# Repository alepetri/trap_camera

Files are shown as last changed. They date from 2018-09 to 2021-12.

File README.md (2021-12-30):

# Raspberry Pi Trap Camera

A custom Trap Camera that uses a Passive Infrared trigger to turn on an Infrared Illuminator and start taking photos via a camera with No IR Filter!

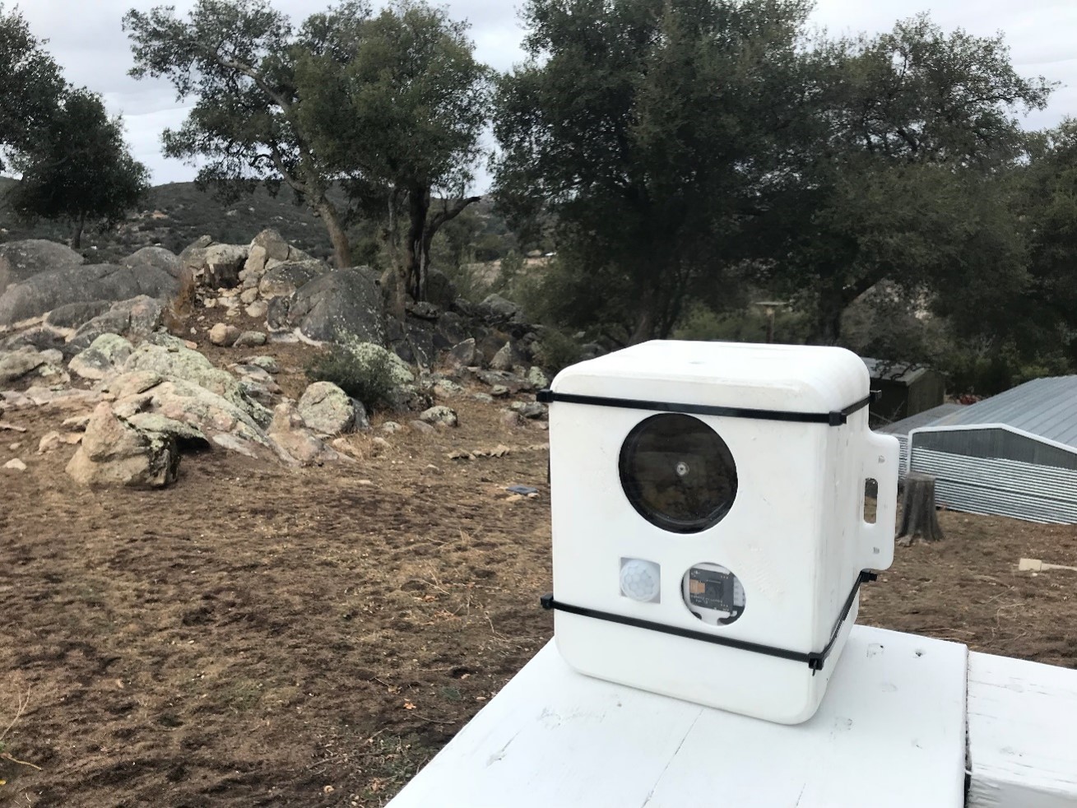
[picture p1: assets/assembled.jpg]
Assembled View


*Gray Fox caught in the act of going through my compost*
Gray Fox in Compost

## Design
Rotation View

Parts List:
- Electronics
    - Raspberry Pi
    - Pi NoIR Camera
    - Passive IR Sensor
    - IR Illuminator
    - 12V Battery
    - Power Relay (GPIO Controllable)
    - 12V to 5V Power Converter
    - Button
    - LED
    - USB External Storage
- Mechanical
    - Polycarbonate Cutouts for Illuminator and Camera
    - O-Ring
    - Pins/ Rods for Hinges
    - Various Fasteners
    - Wiring

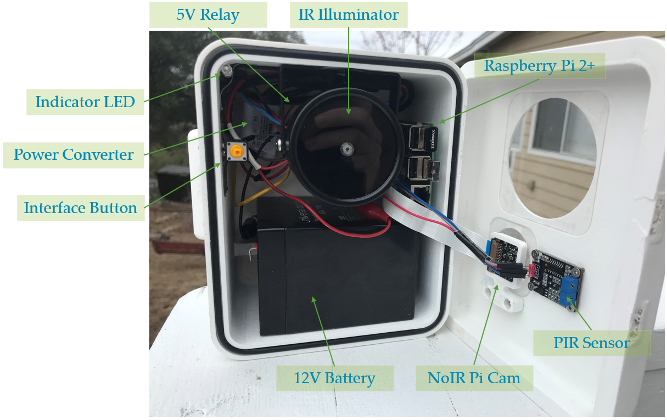
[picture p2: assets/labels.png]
Annotated Veiw


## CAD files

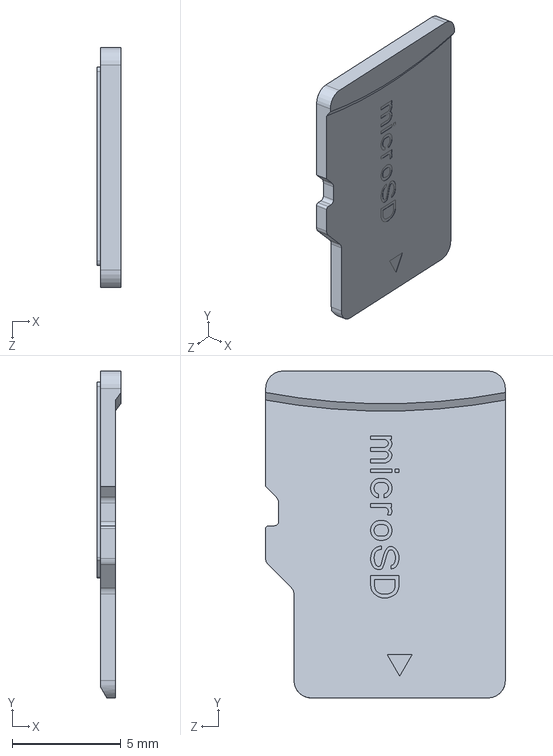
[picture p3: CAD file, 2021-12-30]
CAD/Pi/raspberry_pi_B+_(microsd).SLDASM
1.10 x 15.0 x 11.0 mm

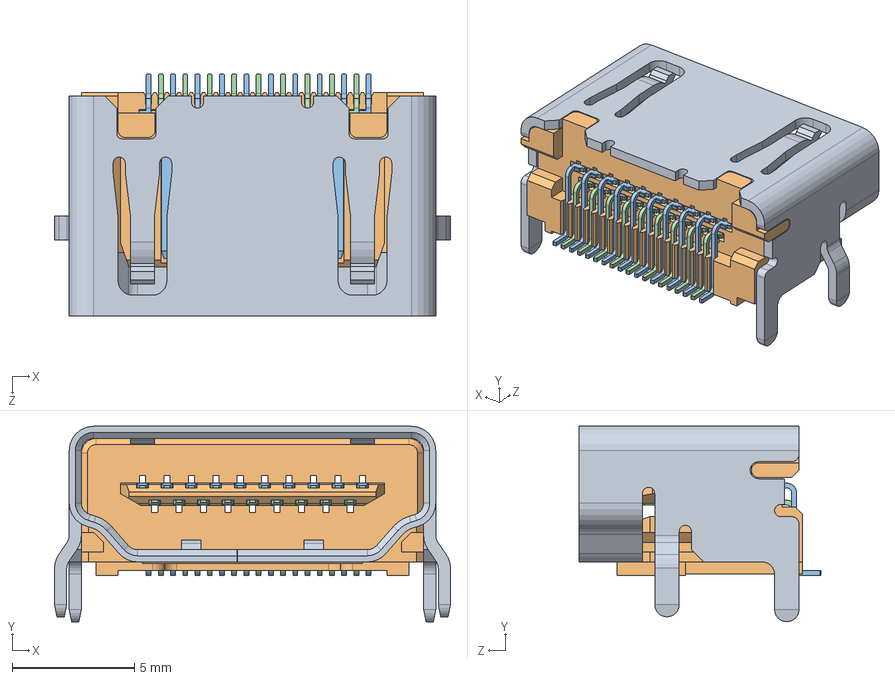
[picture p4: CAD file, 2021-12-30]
CAD/Pi/raspberry_pi_B+_(HDMI_socket).SLDASM
16.2 x 8.00 x 9.90 mm
raspberry_pi__HDMI_socket_cover
raspberry_pi__HDMI_socket_inside
raspberry_pi__HDMI_socket_large_pin x 10
raspberry_pi__HDMI_socket_small_pin x 9

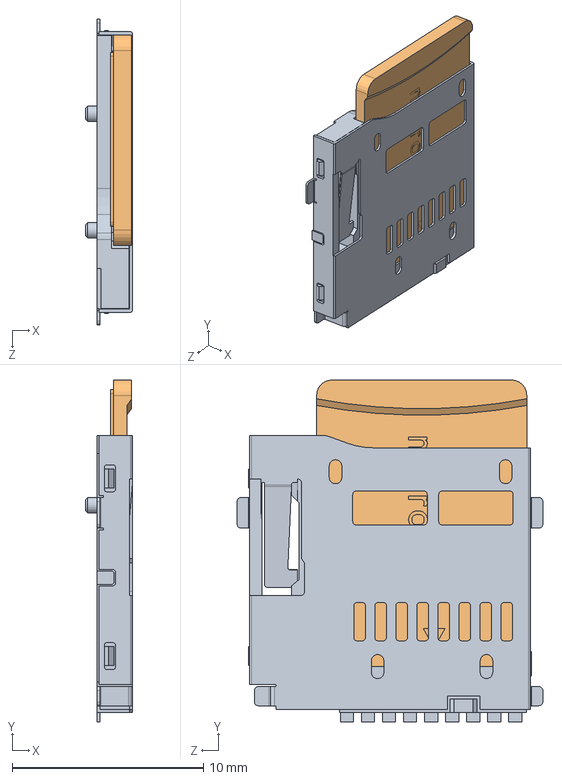
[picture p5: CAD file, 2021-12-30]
CAD/Pi/raspberry_pi_B+_(microsd_slot).SLDASM
2.44 x 17.9 x 16.0 mm
raspberry_pi_B+_(slot)
raspberry_pi_B+_(microsd)

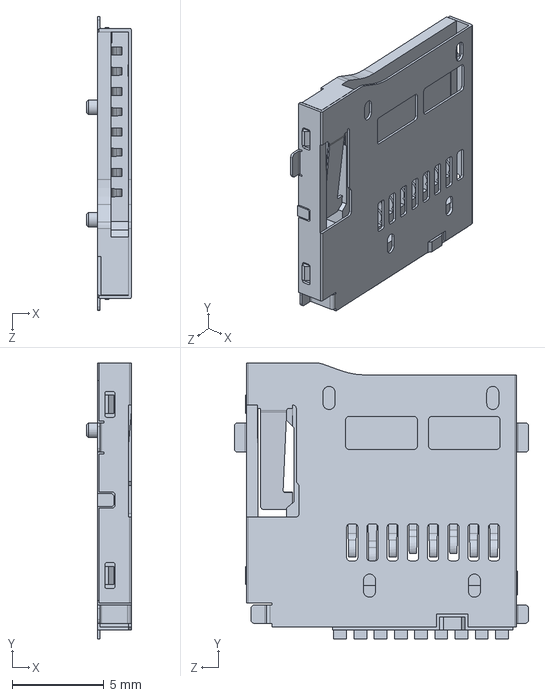
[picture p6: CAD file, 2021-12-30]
CAD/Pi/raspberry_pi_B+_(slot).SLDASM
2.44 x 15.0 x 16.0 mm

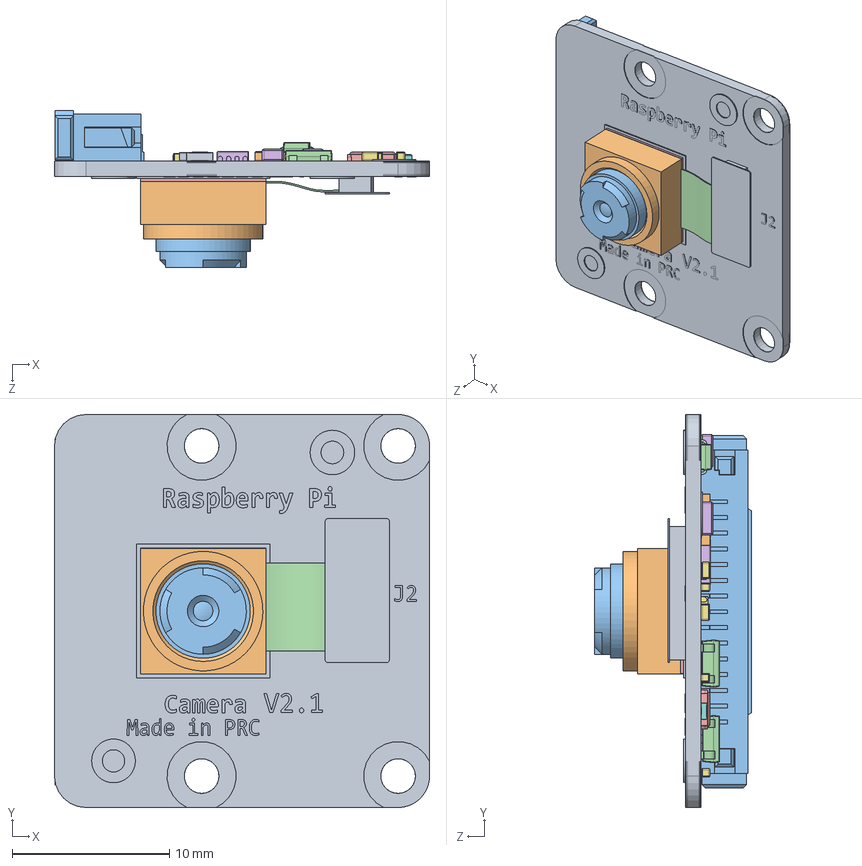
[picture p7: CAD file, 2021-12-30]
CAD/PiCam/RspCameraMia.SLDASM
23.9 x 25.0 x 9.96 mm
PicameraPCB
OVA5647_Housing
OVA5647_Lens_FOV
ribbon_cam
CCD
CAPC-0805-T0.75-BN x 2
CAPC-0402-T0.55-BN x 10
RESC-0402 x 3
RESC-0603 x 2
RESC-1210
c-1-1734248-5-e-raspberry_display
SOT23-5 x 3
KX7 SMD Quartz Crystal Resonator 3.2x2.5mm
c6aaa
4pin_smd x 3

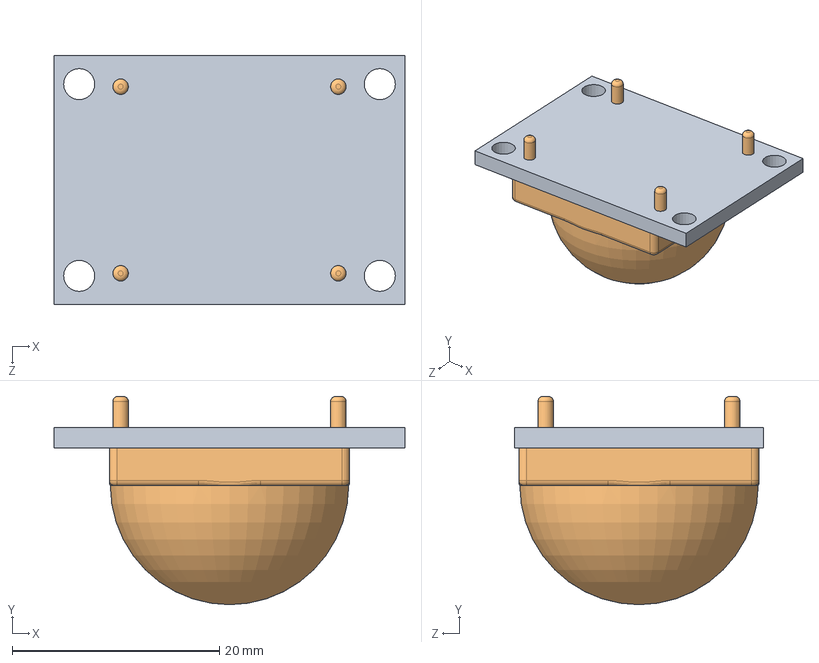
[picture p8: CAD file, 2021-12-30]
CAD/PIR.SLDASM
33.9 x 20.1 x 24.0 mm
sensor
lens

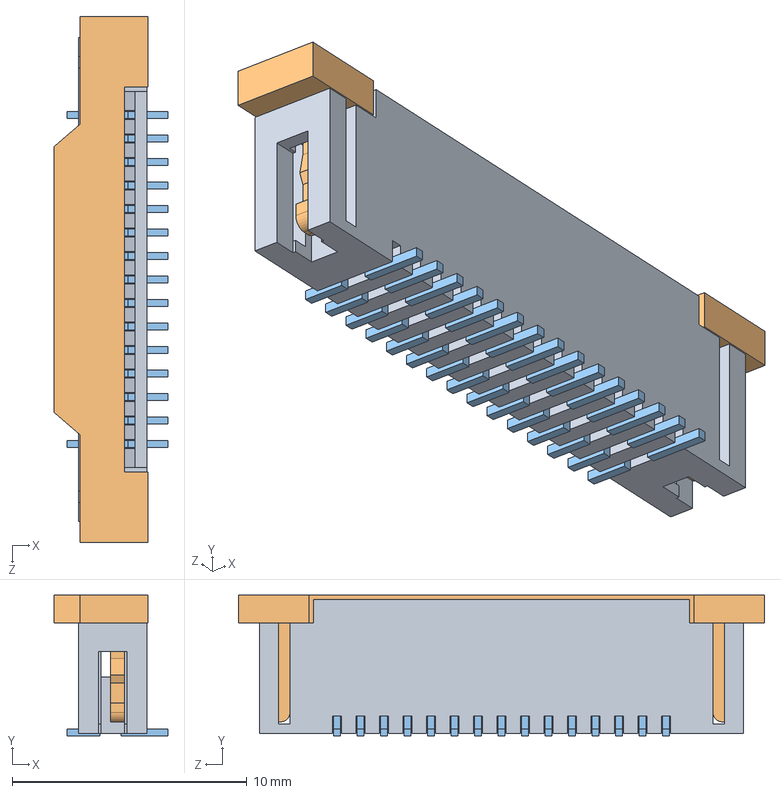
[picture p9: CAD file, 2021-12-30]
CAD/Pi/raspberry_pi_B+_(15_pin_FFC_Connector).SLDASM
4.85 x 6.00 x 22.4 mm
raspberry_pi__15_pin_FFC_Connector_body
raspberry_pi__15_pin_FFC_Connector_locker
raspberry_pi__15_pin_FFC_Connector_pins x 15

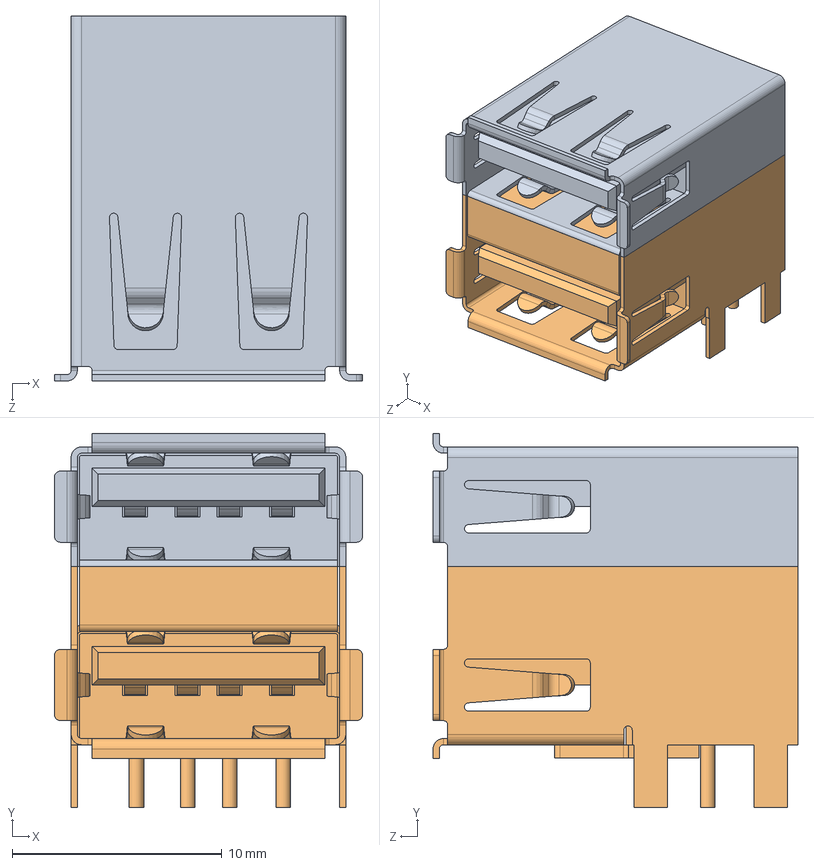
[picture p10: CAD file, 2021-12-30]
CAD/Pi/raspberry_pi_B+_(USB_x2).SLDASM
14.7 x 17.9 x 17.4 mm
raspberry_pi_B+_(USB_x2_part1)
raspberry_pi_B+_(USB_x2_part2)

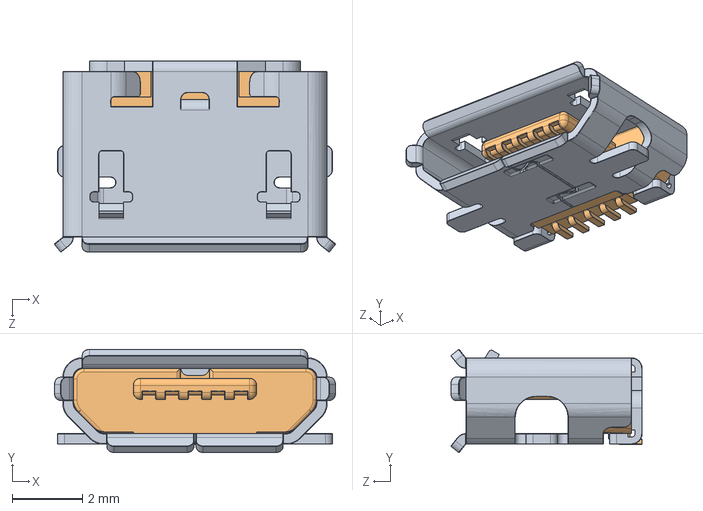
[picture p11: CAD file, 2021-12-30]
CAD/Pi/raspberry_pi_B+_(micro_USB).SLDASM
7.97 x 2.92 x 5.43 mm
raspberry_pi_B+_(micro_USB_cover)
raspberry_pi_B+_(micro_USB_contacts)

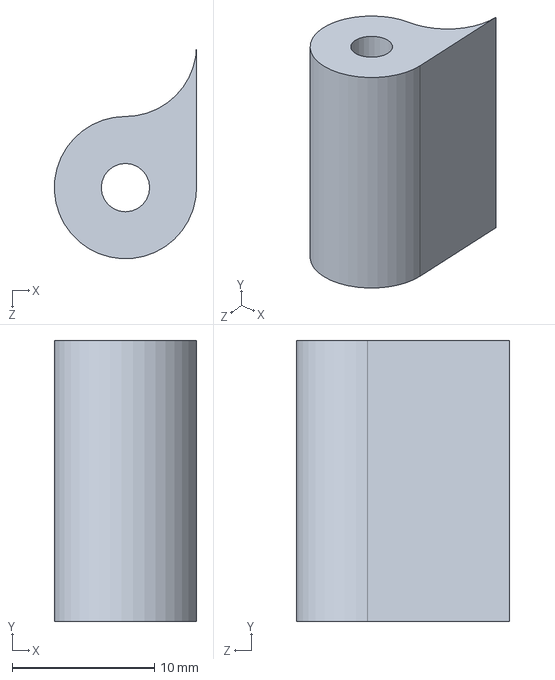
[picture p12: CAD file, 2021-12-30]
CAD/lid_hole_test.SLDPRT
9.99 x 19.8 x 15.0 mm

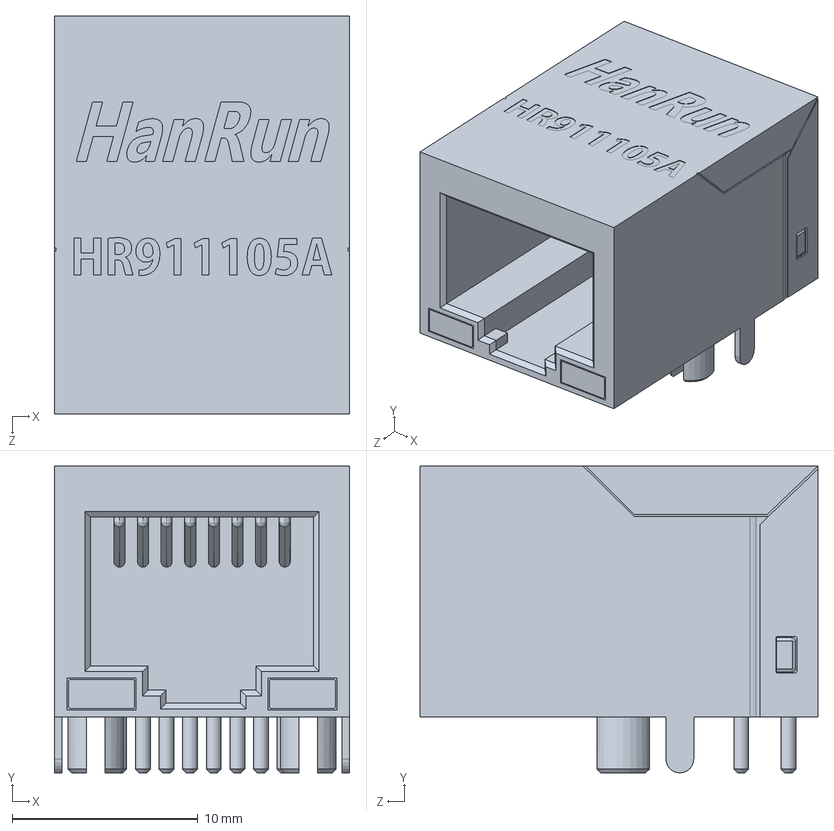
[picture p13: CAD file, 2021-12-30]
CAD/Pi/raspberry_pi_B+_(RJ45).SLDPRT
15.9 x 16.5 x 21.4 mm

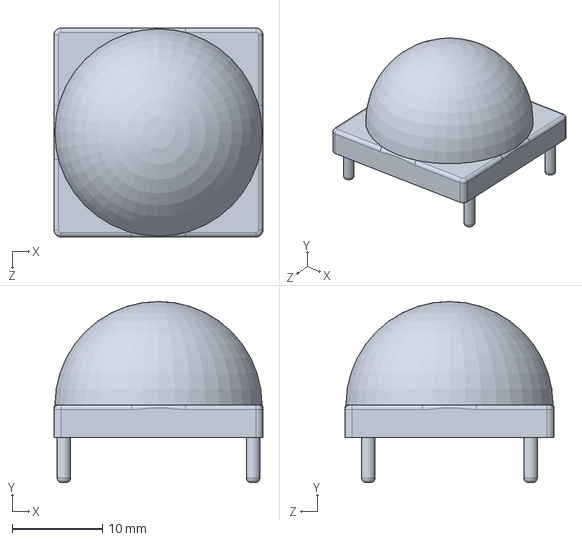
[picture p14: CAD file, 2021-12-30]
CAD/lens.SLDPRT
23.2 x 20.1 x 23.2 mm

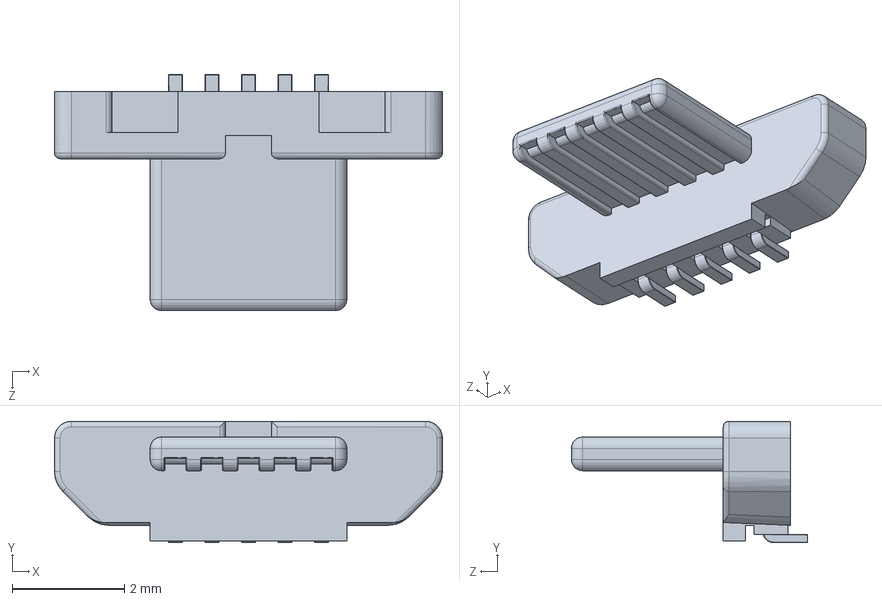
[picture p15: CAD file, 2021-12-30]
CAD/Pi/raspberry_pi_B+_(micro_USB_contacts).SLDPRT
6.90 x 2.16 x 4.20 mm

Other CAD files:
CAD/Pi/raspberry_pi_B+_(P1).SLDASM
CAD/PiCam/RESC-0603.sldprt
CAD/PiCam/ribbon_cam.sldprt
CAD/Terminator.sldprt
CAD/Battery.SLDPRT
CAD/BreakAwayHeaders_3PinShort.sldprt
CAD/BreakAwayHeaders_4PinShort.sldprt
CAD/D1.sldprt
CAD/IR_Illuminator.SLDPRT
CAD/Jumper.sldprt
CAD/PC-817.sldprt
CAD/Pi/raspberry_pi_B+_(168_FBGA_12x12).SLDPRT
CAD/Pi/raspberry_pi_B+_(CI_Board).SLDPRT
CAD/Pi/raspberry_pi_B+_(QFN64).SLDPRT
CAD/Pi/raspberry_pi_B+_(USB_x2_part1).SLDPRT
CAD/Pi/raspberry_pi_B+_(USB_x2_part2).SLDPRT
CAD/Pi/raspberry_pi_B+_(audio_video2).SLDPRT
CAD/Pi/raspberry_pi_B+_(bar_180_2x20).SLDPRT
CAD/Pi/raspberry_pi_B+_(micro_USB_cover).SLDPRT
CAD/Pi/raspberry_pi_B+_(microsd).SLDPRT
CAD/Pi/raspberry_pi_B+_(microsd2).SLDPRT
CAD/Pi/raspberry_pi_B+_(microsd_slot2).SLDPRT
CAD/Pi/raspberry_pi_B+_(slot).SLDPRT
CAD/Pi/raspberry_pi__15_pin_FFC_Connector_body.SLDPRT
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

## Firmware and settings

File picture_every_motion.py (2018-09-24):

# importing camera interface, gpio interface, time, OpenCV2 image processing
from picamera.array import PiRGBArray
from picamera import PiCamera
import time
from datetime import datetime
import cv2
import os
from gpiozero import LED, MotionSensor
import sys

# initializing the camera, gpio pins, and path to save photos
led = LED(17)
pir = MotionSensor(21)
camera = PiCamera()
rawCapture = PiRGBArray(camera)
#camera.resolution = (640, 480)
#camera.framerate = 32
#rawCapture = PiRGBArray(camera, size=(640, 480)))
now = datetime.now()
path = '/media/pi/TRAP_PIX/%02d%02d%04d_%02d_%02d_%02d' % (now.month, now.day, now.year, now.hour, now.minute, now.second)
if not os.path.exists(path):
    os.makedirs(path)

# allows camera time to boot
time.sleep(0.1)

picture_count = 0
photo_taken = False

while picture_count < 400:
    if pir.motion_detected:
        led.on
        if not photo_taken:
            camera.capture(rawCapture, format="bgr")
            img = rawCapture.array
            now = datetime.now()
            current_pic_name = '%02d%02d%04d_%02d_%02d_%02d.jpg' % (now.month, now.day, now.year, now.hour, now.minute, now.second)
            cv2.imwrite(os.path.join(path, current_pic_name), img)
            photo_taken = True
            picture_count += 1
            print('Photos Taken: ' + str(picture_count))
            rawCapture.truncate(0)
    else:
        led.off
        photo_taken = False

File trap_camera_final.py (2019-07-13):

# importing camera interface, gpio interface, time, OpenCV2 image processing
from picamera.array import PiRGBArray
from picamera import PiCamera
import time
from datetime import datetime
import cv2
import os
from gpiozero import LED, MotionSensor, Button
import sys
from subprocess import call

#
def blink(LED, secs_between_blinks, num_blinks):
    count = 0
    while count < num_blinks*2:
        LED.toggle()
        time.sleep(secs_between_blinks/2)
        count += 1
    return

# initializing the gpio pins
ir_illuminator = LED(14, active_high=False)
ir_illuminator.off()
LED_indicator = LED(4)
LED_indicator.off()
passive_infrared = MotionSensor(27)
button = Button(17, hold_time=3)

# initializing the camera
camera = PiCamera()
rawCapture = PiRGBArray(camera)


# initializing unique paths and names to save photos
now = datetime.now()
#path = '/home/pi/Desktop/%02d%02d%04d_%02d_%02d_%02d' % (now.month, now.day, now.year, now.hour, now.minute, now.second)
folder_path = '/media/pi/TRAP_PIX/%02d%02d%04d_%02d_%02d_%02d' % (now.month, now.day, now.year, now.hour, now.minute, now.second)
while not os.path.ismount('/media/pi/TRAP_PIX'):
    print("can't find")
    time.sleep(2)
else:
    print("flash drive found")
    os.makedirs(folder_path)
    print("made folder")

LED_indicator.on()

while not button.is_held:
    pass

blink(LED_indicator, 0.5, 60)
LED_indicator.off()

picture_count = 0
group_number = 0
in_same_group = False
time_at_motion = 0
time_since_motion = 0
while not button.is_held and picture_count < 40000:
    if passive_infrared.motion_detected:
        time_at_motion = time.time()
        ir_illuminator.on()

    time_since_motion = time.time() - time_at_motion

    if time_since_motion < 2:
        if not in_same_group:
            group_number += 1
            in_same_group = True
        camera.capture(rawCapture, format="bgr")
        img = rawCapture.array
        now = datetime.now()
        current_pic_name = 'G%03d_%02d%02d%04d_%02d_%02d_%02d_%02d.jpg' % (group_number, now.month, now.day, now.year, now.hour, now.minute, now.second, now.microsecond)
        cv2.imwrite(os.path.join(folder_path, current_pic_name), img)
        picture_count += 1
        #print('Photos Taken: ' + str(picture_count))
        rawCapture.truncate(0)
    else:
        in_same_group = False
        ir_illuminator.off()

    time.sleep(0.01)

ir_illuminator.off()
blink(LED_indicator, 1, 5)
LED_indicator.off()

call("sudo shutdown -h now", shell=True)

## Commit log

2018-09-25 fixed microsecond bug in video tester
    [tester.py]
2018-11-29 Added Relay and IR Illuminator control tester
2018-11-29 Fixed gpiozero LED on/off reverse
2018-12-05 Solved flashdrive lag problem
    [trap_camera_final.py]
2018-12-05 actually fixed the flashdrive now
    [trap_camera_final.py]
2019-07-25 fixed directory creation and videowriter
    [time_lapse.py]
2019-07-27 Added button and light capabilities
2019-07-27 Got rid of IR Illuminator from time lapse button
2021-12-30 Added CAD
    [4pin_smd.sldprt, 70521906_01.sldprt, 70521906_02.sldprt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]
